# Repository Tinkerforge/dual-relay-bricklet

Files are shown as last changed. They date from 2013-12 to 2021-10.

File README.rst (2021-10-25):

Dual Relay Bricklet
===================

This repository contains the firmware source code and the hardware design
files. The documentation generator configs can be found at
https://github.com/Tinkerforge/generators

Repository Content
------------------

software/:
 * examples/: Examples for all supported languages
 * build/: Compiled files
 * src/: Source code of firmware
 * Makefile: Makefile to build project

hardware/:
 * Contains KiCad project files and additionally schematics as PDF

datasheets/:
 * Contains datasheets for sensors and complex ICs that are used

Hardware
--------

The hardware is designed with the open source EDA Suite KiCad
(http://www.kicad.org). Before you are able to open the files,
you have to install the Tinkerforge kicad-libraries
(https://github.com/Tinkerforge/kicad-libraries). You can either clone
them directly in hardware/ or clone them in a separate folder and
symlink them into hardware/
(ln -s kicad_path/kicad-libraries project_path/hardware). After that you
can open the .pro file in hardware/ with KiCad and from there view and
modify the schematics and the PCB layout.

Software
--------

If you want to do your own Brick/Bricklet firmware development we highly
recommend that you use our build environment setup script and read the
tutorial (https://www.tinkerforge.com/en/doc/Tutorials/Tutorial_Build_Environment/Tutorial.html).

To compile the C code we recommend you to install the newest GNU Arm Embedded
Toolchain (https://launchpad.net/gcc-arm-embedded/+download).
You also need to install bricklib (https://github.com/Tinkerforge/bricklib)
and brickletlib (https://github.com/Tinkerforge/brickletlib).

You can either clone it directly in software/src/ or clone it in a
separate folder and symlink it into software/src/
(ln -s bricklib_path/bricklib project_path/software/src/ and
ln -s brickletlib_path/brickletlib project_path/software/src/).
Finally make sure to have CMake installed
(http://www.cmake.org/cmake/resources/software.html).

After that you can build the firmware by invoking make in software/.
The firmware (.bin) can then be found in software/build/ and uploaded
with brickv (click button "Flashing" on start screen).

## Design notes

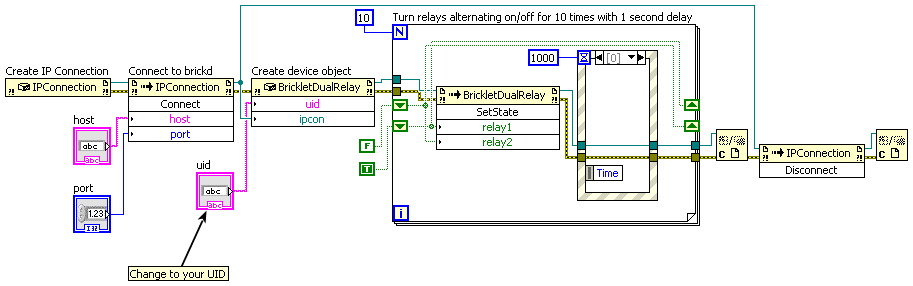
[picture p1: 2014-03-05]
software/examples/labview/Example Simple.vi.png

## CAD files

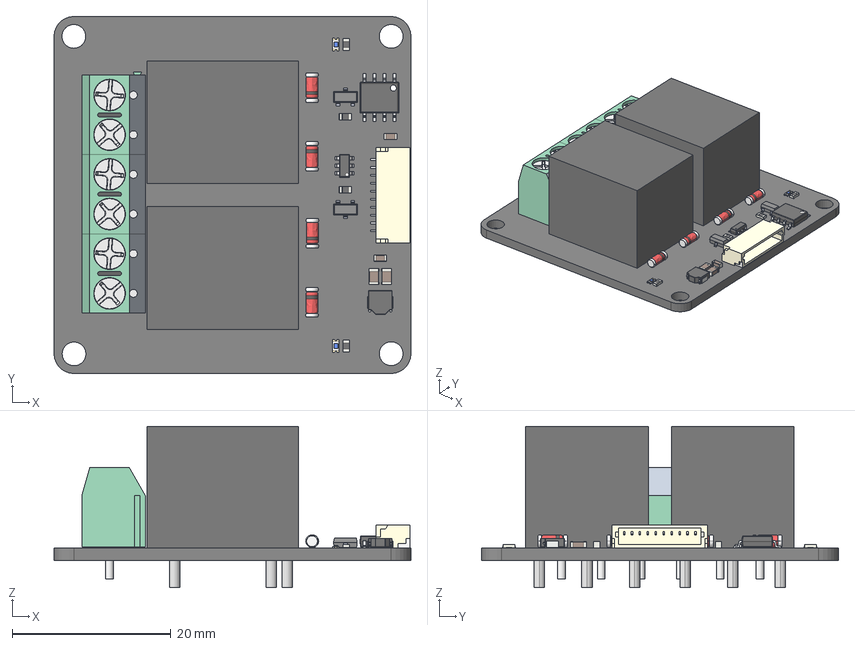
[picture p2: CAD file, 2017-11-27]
hardware/dual-relay.step
45.0 x 45.0 x 20.3 mm

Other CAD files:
hardware/dual-relay.FCStd

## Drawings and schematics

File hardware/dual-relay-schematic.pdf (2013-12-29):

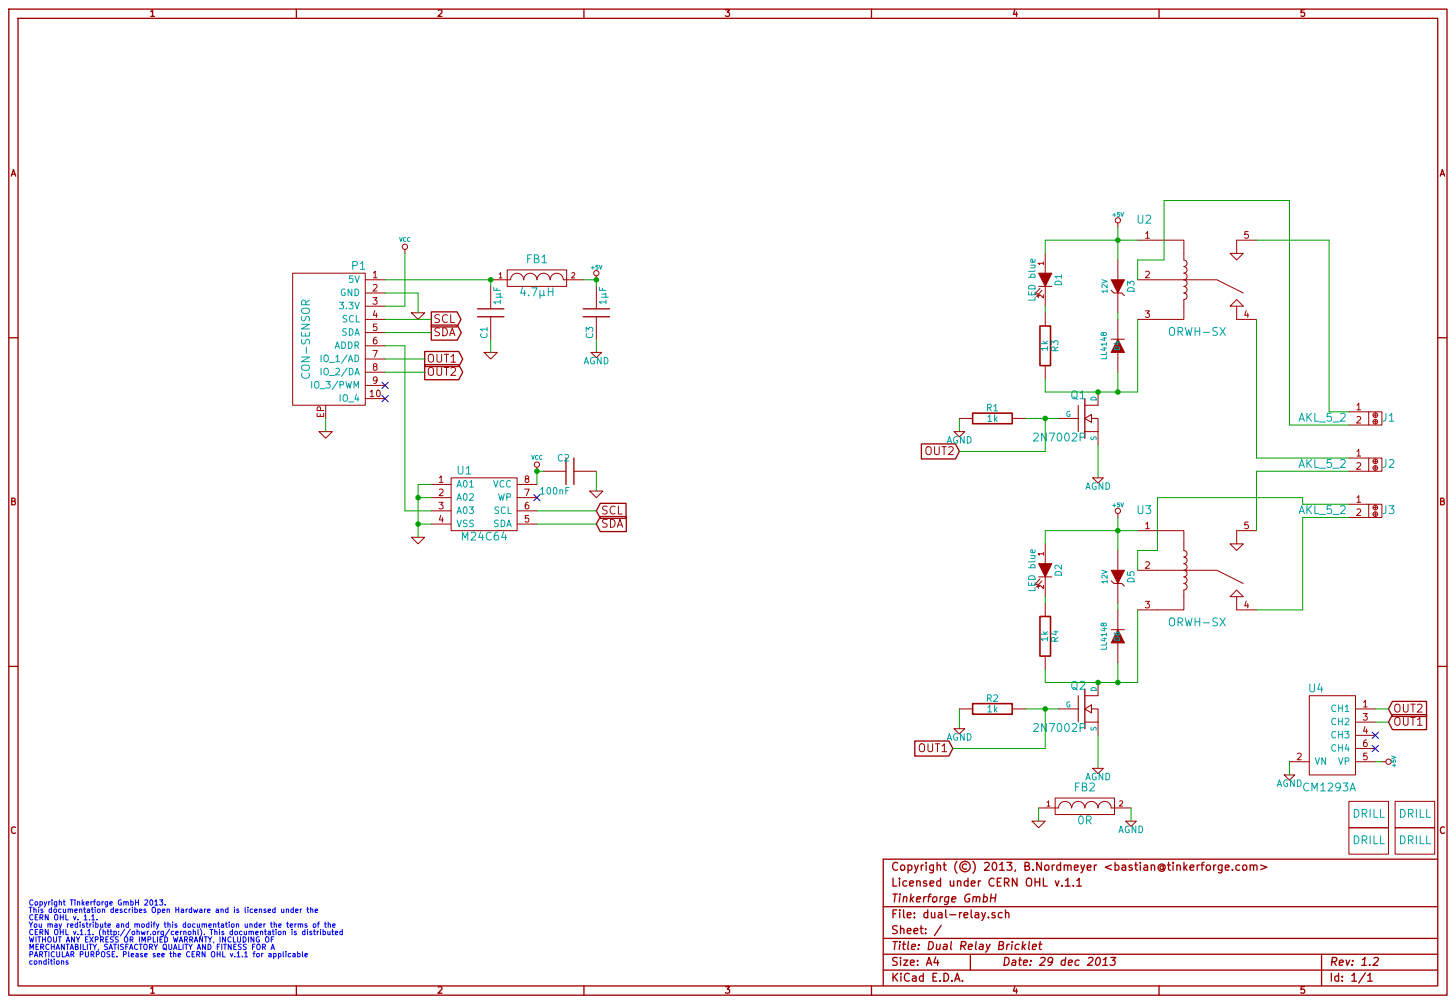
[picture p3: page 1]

Copyright (©) 2013, B.Nordmeyer <bastian@tinkerforge.com>
Licensed under CERN OHL v.1.1
Tinkerforge GmbH
File: dual-relay.sch
Sheet: /
Title: Dual Relay Bricklet

Copyright Tinkerforge GmbH 2013. This documentation describes Open Hardware and is licensed under the CERN OHL v. 1.1. You may redistribute and modify this documentation under the terms of the CERN OHL v.1.1. (http://ohwr.org/cernohl). This documentation is distributed WITHOUT ANY EXPRESS OR IMPLIED WARRANTY, INCLUDING OF MERCHANTABILITY, SATISFACTORY QUALITY AND FITNESS FOR A

PARTICULAR PURPOSE. Please see the CERN OHL v.1.1 for applicable
conditions

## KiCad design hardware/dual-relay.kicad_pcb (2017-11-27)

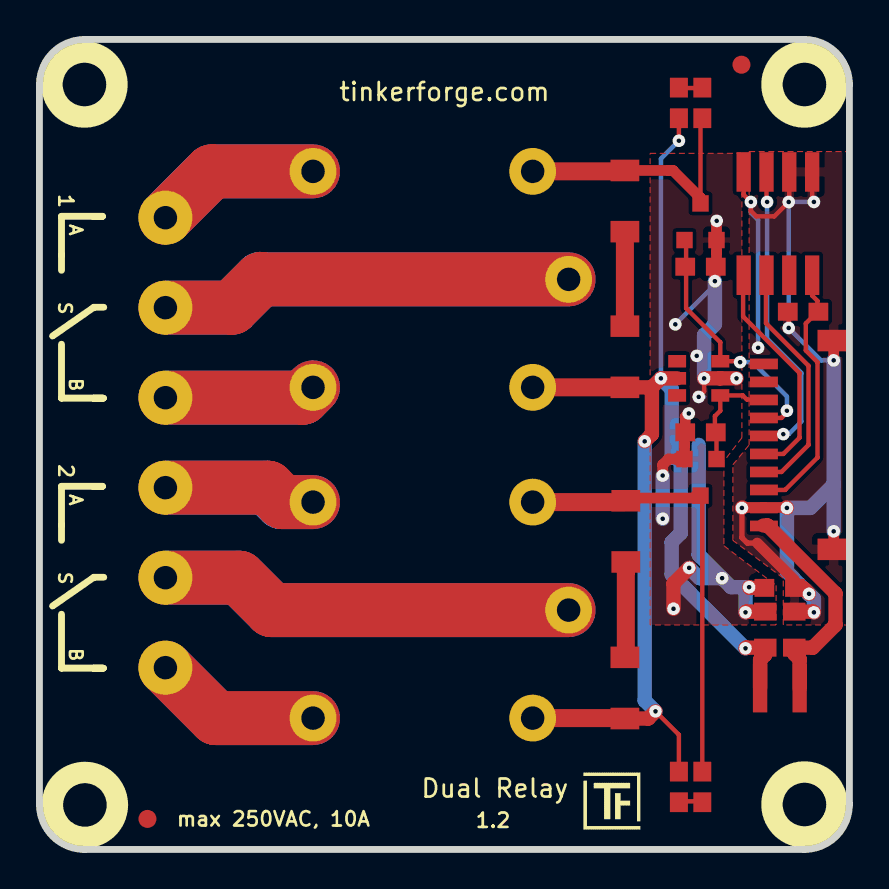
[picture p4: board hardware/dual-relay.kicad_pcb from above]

Board: 2 copper layers, 45.0 x 45.0 mm, 34 parts (0 on the bottom side), 22 nets.

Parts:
C1, C3: 1µF; C0805
C2: 100nF; C0603E
D1, D2: LED blue; D0603E
D3, D5: 12V; MiniMelf
D4, D6: LL4148; MiniMelf
FB1: 4.7µH; NRH3015
FB2: 0R; C0603E
Fiducial_Mark: VAL**; Fiducial_Mark
Fiducial_Mark#2: VAL**; Fiducial_Mark
J1, J2, J3: AKL_5_2
P1: CON-SENSOR
Q1, Q2: 2N7002P; SOT23GDS
R1, R2, R3, R4: 1k; R0603E
Ref**: Val**; Logo_31x31
U1: M24C64; SO-8
U2, U3: ORWH-SX
U4: CM1293A; SC-74
U5, U6, U7, U8: DRILL; DRILL_NP
VAL: CE_5mm
VAL#2: WEEE_7mm

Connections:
+5V: C3.2, D1.1, D2.1, D3.1, D5.1, FB1.2, U2.1, U3.1, U4.5
AGND: C3.1, FB2.2, Q1.S, Q2.S, R1.1, R2.1, U4.2
GND: C1.1, C2.2, FB2.1, P1.2, P1.EP, U1.1, U1.2, U1.4
unnamed: C1.2, FB1.1, P1.1
unnamed: D1.2, R3.1
unnamed: D2.2, R4.1
unnamed: D3.2, D4.2
unnamed: D4.1, Q1.D, R3.2, U2.3
unnamed: D5.2, D6.2
unnamed: D6.1, Q2.D, R4.2, U3.3
unnamed: J1.1, U2.5
unnamed: J1.2, U2.2
unnamed: J2.1, U2.4
unnamed: J2.2, U3.5
unnamed: J3.1, U3.2
unnamed: J3.2, U3.4
unnamed: P1.6, U1.3
OUT1: P1.7, Q2.G, R2.2, U4.3
OUT2: P1.8, Q1.G, R1.2, U4.1
SCL: P1.4, U1.6
SDA: P1.5, U1.5
VCC: C2.1, P1.3, U1.8

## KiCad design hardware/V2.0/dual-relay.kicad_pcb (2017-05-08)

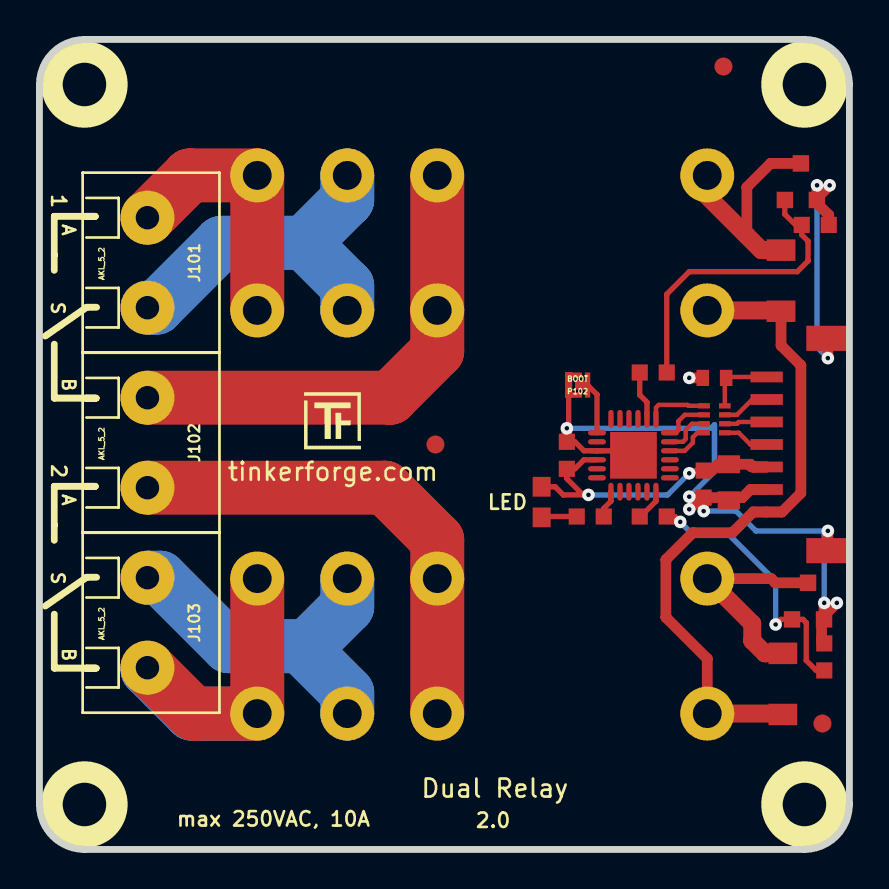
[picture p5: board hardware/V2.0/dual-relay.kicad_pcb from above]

Board: 2 copper layers, 45.0 x 45.0 mm, 31 parts (0 on the bottom side), 26 nets.

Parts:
C101: 1uF; C0603F
C102: 1uF; C0402E
C103: 10uF; C0805
C104: 100nF; C0603F
D101: blue; D0603E
D102, D103: LL4148; MiniMelf
Fiducial_Mark: VAL**; Fiducial_Mark
Fiducial_Mark#2, Fiducial_Mark#3: VAL**; Fiducial_Mark
J101, J102, J103: AKL_5_2
P101: CON-SENSOR2
P102: BOOT; SolderJumper
Q101, Q102: 2N7002P; SOT23GDS
R101: 1k; R0603F
R102, R103: 10; R0603F
R104, R105: 10k; R0603F
REL101, REL102: RELAY_29_127
RP101: TBD; 4X0402
U101: XMC1XXX24; QFN24-4x4mm-0.5mm
U102, U103, U104, U105: DRILL; DRILL_NP
VAL: CE_5mm

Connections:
+5V: D102.2, D103.2, P101.1, REL101.A1, REL102.A1
GND: C101.1, C102.1, C103.1, C104.2, P101.2, P101.EP, P102.1, Q101.S, Q102.S, R104.1, R105.1, U101.9, U101.EXP
unnamed: C102.2, P101.7, RP101.4
unnamed: D101.2, R101.2
unnamed: D102.1, Q101.D, REL101.A2
unnamed: D103.1, Q102.D, REL102.A2
unnamed: J101.1, REL101.2, REL101.5
unnamed: J101.2, REL101.3, REL101.4
unnamed: J102.1, REL102.1, REL102.6
unnamed: J102.2, REL101.1, REL101.6
unnamed: J103.1, REL102.3, REL102.4
unnamed: J103.2, REL102.2, REL102.5
unnamed: P101.4, RP101.1
unnamed: P101.5, RP101.2
unnamed: P101.6, RP101.3
unnamed: P102.2, U101.7
unnamed: Q101.G, R102.1, R104.2
unnamed: Q102.G, R103.1, R105.2
unnamed: R101.1, U101.13
RELAY0: R103.2, U101.18
RELAY1: R102.2, U101.2
S-CLK: RP101.7, U101.23
S-CS: RP101.8, U101.22
S-MISO: RP101.5, U101.1
S-MOSI: RP101.6, U101.24
VCC: C101.2, C103.2, C104.1, D101.1, P101.3, U101.10

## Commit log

2011-08-25 initial hardware source commit
    [dual-relay.brd, dual-relay.sch]
2012-02-13 checkin of version V1.1 - remove resistor in address line - add fiducial markers - increase copper distances
    [dual-relay.brd, dual-relay.sch]
2013-12-29 checkin of new hardware files version 1.2
    [dual-relay.brd, dual-relay.kicad_pcb, dual-relay.sch]
2014-01-08 delphi: Make example toggle the relays
2014-01-08 shell: Make example toggle the relays
2014-04-02 perl: Unify print style
2015-08-07 Use full device class name in Python example
2016-05-18 c: Add missing device destroy call
2016-06-17 change design for better production
    [dual-relay.kicad_pcb, dual-relay.sch]
2016-06-17 more improvements
    [dual-relay.kicad_pcb]
2017-04-28 prototype of new version
    [dual-relay.kicad_pcb, dual-relay.sch]
2017-05-04 change filtering to r/c circuit
    [dual-relay.kicad_pcb, dual-relay.sch]
2017-05-04 add fiducials, logos, protection diodes
    [dual-relay.kicad_pcb, dual-relay.sch]
2017-05-08 add description
    [dual-relay.kicad_pcb]
2017-11-27 Add 3d information (final)
    [dual-relay.kicad_pcb, dual-relay.sch]
2017-11-27 Add 3d model (*.step & *.FCStd)
    [dual-relay.FCStd, dual-relay.step]
2018-02-20 Cleanup KiCad libraries config
    Ensure LibDir=kicad-libraries and LibName1=tinkerforge.
    Remove special library.
2021-10-25 Update KiCad link
    https://www.kicad.org/blog/2021/10/Avoid-links-to-former-kicad-domain/

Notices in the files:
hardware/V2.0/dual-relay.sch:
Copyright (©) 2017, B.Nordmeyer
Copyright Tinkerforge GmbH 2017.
